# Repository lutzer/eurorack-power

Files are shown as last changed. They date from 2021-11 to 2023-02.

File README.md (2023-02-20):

# Eurorack Power Supplies

schematics for eurorack power supplies

## Setup

* copy libraries from *schematics/libraries* to eagle libraries folder
* copy schematics to eagle project folder
* open project
* activate libraries with right click and *use* in library manager

## Notes

* To avoid oscillation problems when using DKMW30f-12:
  * Replace R6 with wired connection
  * Don't solder in C3

## BOM

### DC DC Converter Options

#### 12V

* 30W: https://www.mouser.de/ProductDetail/MEAN-WELL/DKMW30F-12/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
* 15W: https://www.mouser.de/ProductDetail/MEAN-WELL/DKMW15F-12/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

#### 5V

* 1A: https://www.reichelt.de/dc-dc-wandler-tsr-1-1-w-5-v-1000-ma-sil-to-220-tsr-1-2450-p116850.html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

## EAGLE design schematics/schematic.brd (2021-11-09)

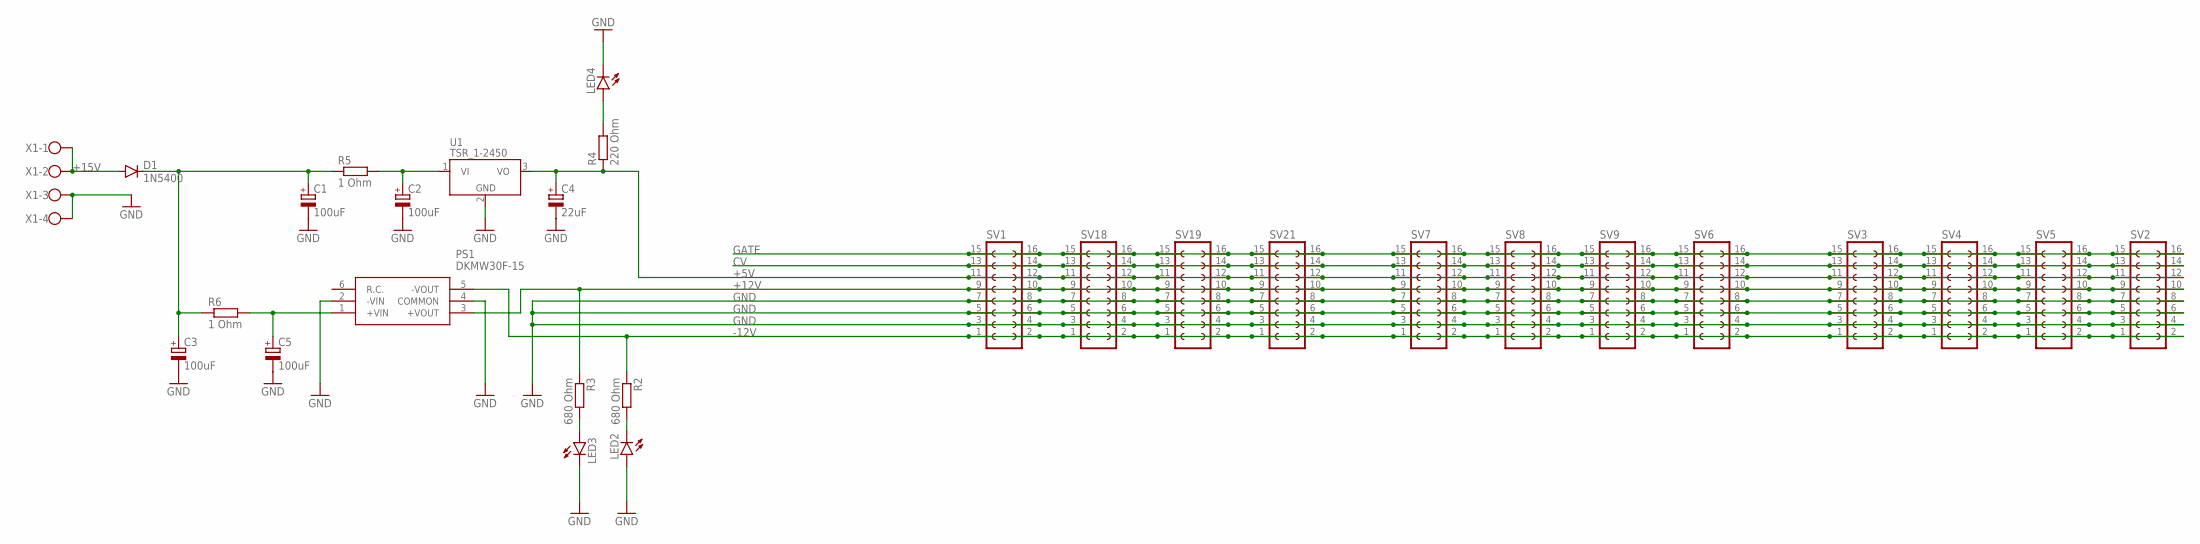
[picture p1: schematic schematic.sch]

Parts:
C1, C2, C3, C5: 100uF; E3,5-8
C4: 22uF; E2,5-5
D1: 1N5400; DO201-15
LED2, LED3, LED4: LED3MM
PS1: DKMW30F-15; DKMW30F15
R2, R3: 680 Ohm; 0207/10
R4: 220 Ohm; 0207/10
R5, R6: 1 Ohm; 0207/10
SV1, SV2, SV3, SV4, SV5, SV6, SV7, SV8, SV9, SV18, SV19, SV21: FE08-2
U1: TSR_1-2450; TSR-1
X1: W237-4

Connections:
+5V: C4.+, R4.1, SV1.11, SV1.12, SV2.11, SV2.12, SV3.11, SV3.12, SV4.11, SV4.12, SV5.11, SV5.12, SV6.11, SV6.12, SV7.11, SV7.12, SV8.11, SV8.12, SV9.11, SV9.12, SV18.11, SV18.12, SV19.11, SV19.12, SV21.11, SV21.12, U1.3 (VO)
+12V: PS1.3 (+VOUT), R3.1, SV1.9, SV1.10, SV2.9, SV2.10, SV3.9, SV3.10, SV4.9, SV4.10, SV5.9, SV5.10, SV6.9, SV6.10, SV7.9, SV7.10, SV8.9, SV8.10, SV9.9, SV9.10, SV18.9, SV18.10, SV19.9, SV19.10, SV21.9, SV21.10
+15V: D1.A, X1.1, X1.2
-12V: PS1.5 (-VOUT), R2.1, SV1.1, SV1.2, SV2.1, SV2.2, SV3.1, SV3.2, SV4.1, SV4.2, SV5.1, SV5.2, SV6.1, SV6.2, SV7.1, SV7.2, SV8.1, SV8.2, SV9.1, SV9.2, SV18.1, SV18.2, SV19.1, SV19.2, SV21.1, SV21.2
CV: SV1.13, SV1.14, SV2.13, SV2.14, SV3.13, SV3.14, SV4.13, SV4.14, SV5.13, SV5.14, SV6.13, SV6.14, SV7.13, SV7.14, SV8.13, SV8.14, SV9.13, SV9.14, SV18.13, SV18.14, SV19.13, SV19.14, SV21.13, SV21.14
GATE: SV1.15, SV1.16, SV2.15, SV2.16, SV3.15, SV3.16, SV4.15, SV4.16, SV5.15, SV5.16, SV6.15, SV6.16, SV7.15, SV7.16, SV8.15, SV8.16, SV9.15, SV9.16, SV18.15, SV18.16, SV19.15, SV19.16, SV21.15, SV21.16
GND: C1.-, C2.-, C3.-, C4.-, C5.-, LED2.A, LED3.K (C), LED4.K (C), PS1.2 (-VIN), PS1.4 (COMMON), SV1.3, SV1.4, SV1.5, SV1.6, SV1.7, SV1.8, SV2.3, SV2.4, SV2.5, SV2.6, SV2.7, SV2.8, SV3.3, SV3.4, SV3.5, SV3.6, SV3.7, SV3.8, SV4.3, SV4.4, SV4.5, SV4.6, SV4.7, SV4.8, SV5.3, SV5.4, SV5.5, SV5.6, SV5.7, SV5.8, SV6.3, SV6.4, SV6.5, SV6.6, SV6.7, SV6.8, SV7.3, SV7.4, SV7.5, SV7.6, SV7.7, SV7.8, SV8.3, SV8.4, SV8.5, SV8.6, SV8.7, SV8.8, SV9.3, SV9.4, SV9.5, SV9.6, SV9.7, SV9.8, SV18.3, SV18.4, SV18.5, SV18.6, SV18.7, SV18.8, SV19.3, SV19.4, SV19.5, SV19.6, SV19.7, SV19.8, SV21.3, SV21.4, SV21.5, SV21.6, SV21.7, SV21.8, U1.2 (GND), X1.3, X1.4
unnamed: LED2.K (C), R2.2
unnamed: LED3.A, R3.2
unnamed: LED4.A, R4.2
unnamed: C1.+, C3.+, D1.C, R5.1, R6.1
VI: C2.+, R5.2, U1.1 (VI)
VI1: C5.+, PS1.1 (+VIN), R6.2

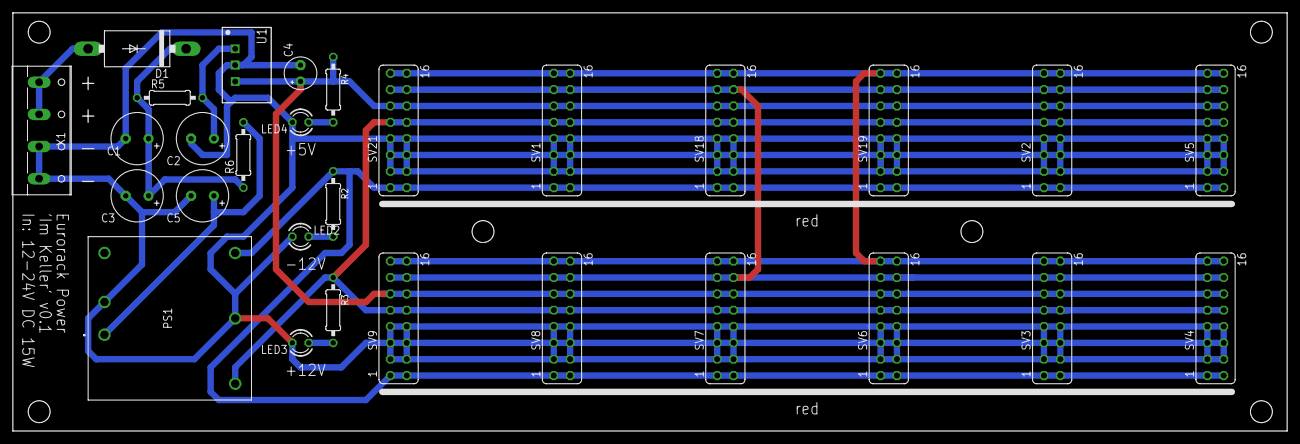
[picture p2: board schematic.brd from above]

Board: 2 copper layers, 198.1 x 65.0 mm, 29 parts (0 on the bottom side), 13 nets.

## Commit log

2021-02-09 added schematic
    [schematic.sch]
2021-02-14 added eagle copy script
    [schematic.sch]
2021-02-15 changed schematic
    [schematic.sch]
2021-02-15 fixed power header connections
    [schematic.sch]
2021-02-16 added first board layout
    [schematic.brd, schematic.sch]
2021-02-16 added drillholes and descriptions
    [schematic.brd]
2021-02-17 added double input screw terminals
    [schematic.brd, schematic.sch]
2021-02-17 removed airwire errors
    [schematic.brd, schematic.sch]
2021-02-17 added stripe mark
    [schematic.brd, schematic.sch]
2021-02-17 replaced dc dc converter with smaller 15W version
    [schematic.brd, schematic.sch]
2021-02-18 removed airwires, added dkmw30f lib
    [schematic.brd]
2021-02-18 added 2 crc groups
    [schematic.brd, schematic.sch]
2021-02-19 changed distance of power headers
    [schematic.brd]
2021-02-20 fixed wire clearance
    [schematic.brd]
2021-11-09 added 4 more headers to board
    [schematic.brd, schematic.sch]
2021-11-09 some minor fixes on schematic
    [schematic.brd]
